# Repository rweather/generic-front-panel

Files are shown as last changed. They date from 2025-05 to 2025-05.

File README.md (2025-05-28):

Generic Front Panel
===================

This repository contains schematics and other information for a generic
front panel for 8-bit homebrew computers.

Here it is connected to my version of
[Ben Eater's 6502 Breadboard Computer](https://eater.net/6502),
running the "hello.s" example from the "src/6502" directory.
It is shown here after I typed ABCDEF on the keypad:

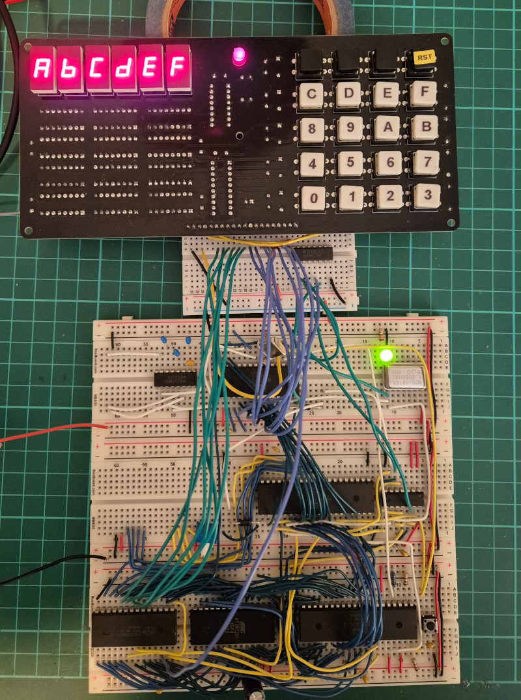
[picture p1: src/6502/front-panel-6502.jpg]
Front Panel Connected to 6502 Computer


Here is a close-up of the front panel with a 3D-printed plate over the top:

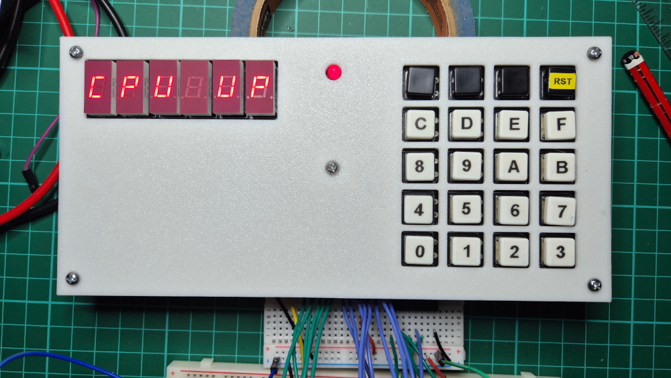
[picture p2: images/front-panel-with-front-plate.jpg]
Front Panel with Front Plate


The "print" directory contains an OpenSCAD file for the 3D-printable plate.
My brother, who is into 3D-printing, has a textured print bed for his printer.
He printed the plate upside down and the texturing gave the plate a nice finish.

## Features

The generic front panel has the following features:

* 6-digit seven segment display.
* 16-digit hexadecimal keypad.
* 3 extra keys for "CMD1", "CMD2", and "CMD3" which can be assigned
  any commands you like by your software.
* 1 extra key for a system reset button.
* 20-pin connector to the rest of your homebrew system.
* Power LED for the 5V power rail.

Note that this front panel requires software support.  It doesn't directly
operate the address bus, data bus, clock, and other control lines like
front panels of old.

What this front panel does do is make it easy to write a memory monitor in
software that can examine memory, modify memory, single-step, and so on.
The 6 displays can display a 16-bit address and an 8-bit byte.  Or anything
else you like, even words.

The seven segment displays, keypad buttons, and power LED are mounted
on the front side of the PCB.  All other components are mounted on the
back side.  The inline current limiting resistors are specified as 8-way
resistor arrays.  However, you could fit 8 regular resistors side by side
instead.

The front panel draws about 250mA from the 5V rail when all 48 segments
in the 7-segment displays and the power LED are lit.  About 5mA per segment.

I have provided drivers and examples for various CPU's under the
"src" directory.  Patches welcome for other CPU's and homebrew boards.

## Schematic and gerber files

* [PDF of the schematic](schematics/Generic_Front_Panel/PDF/Generic_Front_Panel.pdf)
* [Gerber files for manufacture](schematics/Generic_Front_Panel/Gerbers)

The dimensions of the PCB are 195mm x 90mm.  Five 3mm mounting holes are
provided for mounting behind a face plate: four corners and one in the
centre for added strength.

## Parts list

* 1 x Generic Front Panel FP-01 PCB
* 1 x 74HC138 3-line to 8-line decoder (74LS138 or 74HCT138 can be substituted)
* 1 x 74HC244 octal buffer / line driver (74LS244 or 74HCT244 can be substituted)
* 6 x 74HC259 addressable latch (74LS259 or 74HCT239 can be substituted)
* 6 x 100nF ceramic or monolithic capacitor
* 5 x 100pF ceramic capacitor
* 1 x 100uF electrolytic capacitor, rated for 6.3V or better
* 6 x 470 ohm DIP-16 resistor array
* 5 x 4.7K ohm resistor
* 1 x 220 ohm resistor (series resistor for 5mm power LED, adjust value for the LED's current rating)
* 1 x 5mm LED for the power LED (color is up to you)
* 6 x MAN71A 7-segment LED display (TIL-312 or Broadcom 5082-7611 can be substituted)
* 5 x 1N4148 diode
* 20 x 12mm push button plus keycaps
* 1 x 20-pin 2.54mm pitch terminal header or socket for the J1 connector

I recommend using DIP-14 sockets for the 7-segment LED displays to
raise the height of the displays up to roughly level with the top of the
push buttons plus keycaps.  Sockets for the other IC's are up to you;
I didn't bother.

Labels can be applied to the keycaps using a label maker and clear labels.

This is what the front and back of the PCB looks like once assembled
(I had only done a very basic board clean at this point so it is still a
little smudgy):

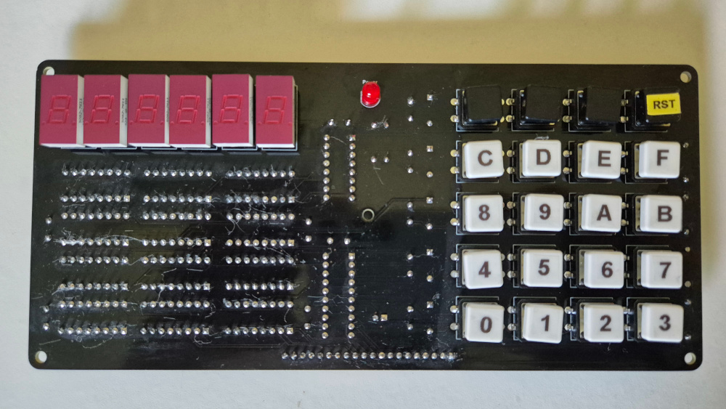
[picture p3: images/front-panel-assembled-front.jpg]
Front Panel Assembled Front


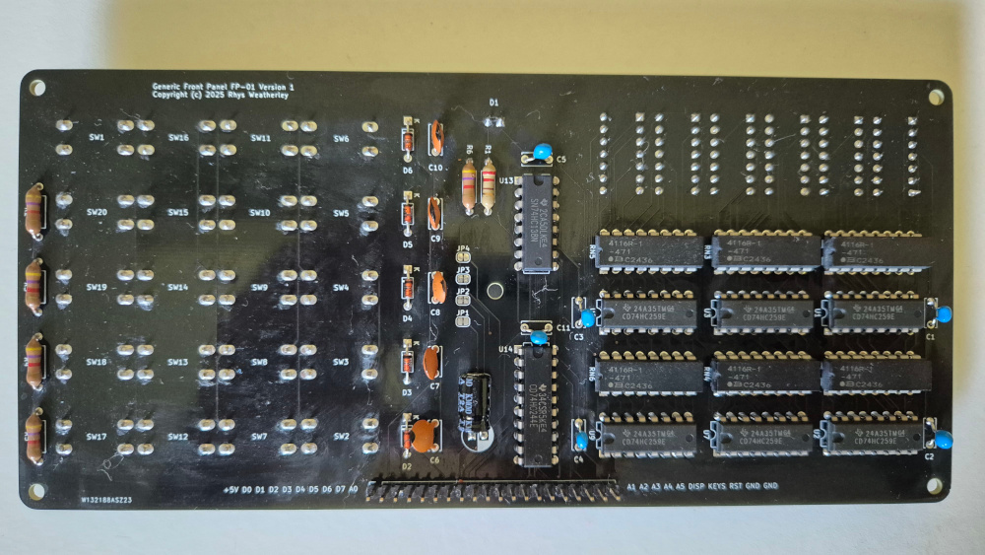
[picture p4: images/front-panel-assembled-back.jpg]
Front Panel Assembled Back


## 20-pin connector

The connector on the bottom of the PCB has the following pins:

<table border="1">
<tr><td><b>Pin</b></td><td><b>Description</b></td></tr>
<tr><td>1</td><td>+5V</td></tr>
<tr><td>2</td><td>D0</td></tr>
<tr><td>3</td><td>D1</td></tr>
<tr><td>4</td><td>D2</td></tr>
<tr><td>5</td><td>D3</td></tr>
<tr><td>6</td><td>D4</td></tr>
<tr><td>7</td><td>D5</td></tr>
<tr><td>8</td><td>D6</td></tr>
<tr><td>9</td><td>D7</td></tr>
<tr><td>10</td><td>A0</td></tr>
<tr><td>11</td><td>A1</td></tr>
<tr><td>12</td><td>A2</td></tr>
<tr><td>13</td><td>A3</td></tr>
<tr><td>14</td><td>A4</td></tr>
<tr><td>15</td><td>A5</td></tr>
<tr><td>16</td><td>Select Display (active low)</td></tr>
<tr><td>17</td><td>Select Keypad (active low)</td></tr>
<tr><td>18</td><td>Reset (active low)</td></tr>
<tr><td>19</td><td>GND</td></tr>
<tr><td>20</td><td>GND</td></tr>
</table>

## Chip selects

To interface to your homebrew computer, you will need to provide address
decoding for the two "chip select" lines "Select Display" and "Select Keypad".

You can put the front panel anywhere in memory or I/O space that is
aligned on a 64-byte boundary.  Only the bottom 6 address bits are
provided to the front panel.  You need to decode the upper 10 bits
(of a 16-bit address) yourself by some means.

"Select Display" should be low when the top-most bits of the address
match the location in memory where you want to put the display,
and when the bus is in a write cycle.  The display occupies 64 bytes
of memory space.

"Select Keypad" should be low when the top-most bits of the address
match the location in memory where you want to put the keypad,
and when the bus is in a read cycle.  The keypad occupies 32 bytes
of memory space.  It can overlap with the display in memory if that
is easier.

## Writing to the display

Each segment of the display has its own memory address.  Each digit
occupies 8 bytes of memory space, for the segments A, B, C, D, E, F, G,
and decimal point.  The displays are at offsets 0, 8, 16, 24, 32,
and 40 in the memory space.

Write a byte with the low bit set to 0 to a segment's address to turn
the segment on, or write a byte with the low bit set to 1 to turn the
segment off.  The segment will stay lit until modified or the power is
turned off.  The display is not multiplexed so there is no need to
constantly refresh.

Writing any byte value to offset 56 will turn all segments on.
This can be useful for testing.  Normally you will want to turn
everything off at startup time.

The "one byte per segment" design was borrowed from the Heathkit ET-3400.
74HC259 addressable latches are used to individually address each segment,
and to remember the state of the segment between writes.

## Reading from the keypad

The keypad consists of 5 rows of 4 keys.  The rows are associated with
address bits A0 to A4.  Scan through the keypad one row at a time,
setting one address bit to 0 and the rest to 1.  When you read from that
address, the bits that are set to zero indicate which keys are pressed
on that row.

<table border="1">
<tr><td><b>Address</b></td><td><b>Bit</b></td><td><b>Key</b></td></tr>
<tr><td>$XX1E (A0)</td><td>0</td><td>0</td></tr>
<tr><td>$XX1E (A0)</td><td>1</td><td>1</td></tr>
<tr><td>$XX1E (A0)</td><td>2</td><td>2</td></tr>
<tr><td>$XX1E (A0)</td><td>3</td><td>3</td></tr>
<tr><td>$XX1D (A1)</td><td>0</td><td>4</td></tr>
<tr><td>$XX1D (A1)</td><td>1</td><td>5</td></tr>
<tr><td>$XX1D (A1)</td><td>2</td><td>6</td></tr>
<tr><td>$XX1D (A1)</td><td>3</td><td>7</td></tr>
<tr><td>$XX1B (A2)</td><td>0</td><td>8</td></tr>
<tr><td>$XX1B (A2)</td><td>1</td><td>9</td></tr>
<tr><td>$XX1B (A2)</td><td>2</td><td>A</td></tr>
<tr><td>$XX1B (A2)</td><td>3</td><td>B</td></tr>
<tr><td>$XX17 (A3)</td><td>0</td><td>C</td></tr>
<tr><td>$XX17 (A3)</td><td>1</td><td>D</td></tr>
<tr><td>$XX17 (A3)</td><td>2</td><td>E</td></tr>
<tr><td>$XX17 (A3)</td><td>3</td><td>F</td></tr>
<tr><td>$XX0F (A4)</td><td>0</td><td>CMD1</td></tr>
<tr><td>$XX0F (A4)</td><td>1</td><td>CMD2</td></tr>
<tr><td>$XX0F (A4)</td><td>2</td><td>CMD3</td></tr>
<tr><td>$XX0F (A4)</td><td>3</td><td>(not used)</td></tr>
</table>

The "Reset" key is special.  It will pull pin 18 on the connector
down to GND when pressed.  It is assumed that a pull-up resistor and
debouncing capacitor are present on your main computer board.
If you want to use "Reset" for something else (such as a "CMD4" key),
you can connect pin 18 to an I/O pin on your main computer board.

The "rows as addresses" design was borrowed from the VZ200 / Laser 200.
Only a single 74HC244 bus transceiver is required to read the keypad.
Everything else is pushbuttons, diodes, resistors, and capacitors.

There are jumpers on the back of the board that can be cut to wire
up additional keys if you need more than 20.  The extra keys will
be available as bits 4 through 7.  The bits are pulled high if the
jumpers are uncut.

## License

MIT License.

## Contact

For more information on this project, to report bugs, or to suggest
improvements, please contact the author Rhys Weatherley via
[email](mailto:rhys.weatherley@gmail.com).

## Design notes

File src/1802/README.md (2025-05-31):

This directory contains driver code for 1802-based machines in "fp\_driver.asm".

The front panel should be wired up to the 1802 microprocessor as follows:

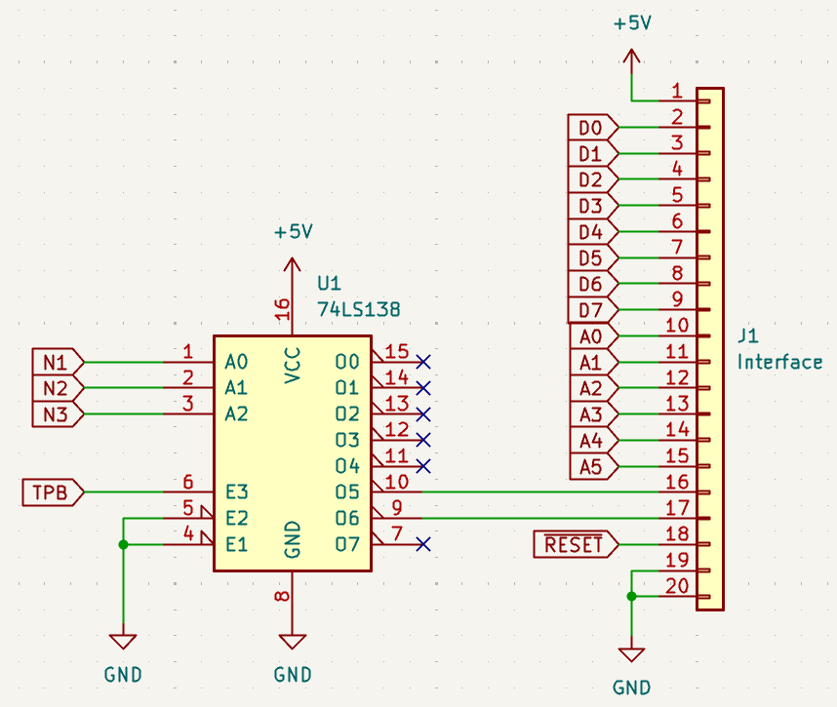
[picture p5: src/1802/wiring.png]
Wiring for 1802


Output 5 is used for the display and input 6 is used for the keypad.
If you change these, then modify the "FP\_PORT\_OUT" and "FP\_PORT\_IN"
definitions in "fp\_driver.asm".

The "hello.asm" example scrolls "HELLORLD!" followed by the printable ASCII
characters across the display from right to left.

Press any key except RESET to stop the scrolling message.  Keys pressed
after that (except RESET) will be shown on the display, scrolling in from
the right.  This allows all keys on the keypad to be tested.  Press RESET
to start again with the scrolling message.

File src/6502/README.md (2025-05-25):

This directory contains driver code for 6502-based machines in "fp\_driver.s".

The "hello.s" example is designed to work with
[Ben Eater's 6502 Breadboard Computer](https://eater.net/6502), with the
front panel placed at address $4000 in memory.  The front panel should be
wired up to the breadboard computer as follows:

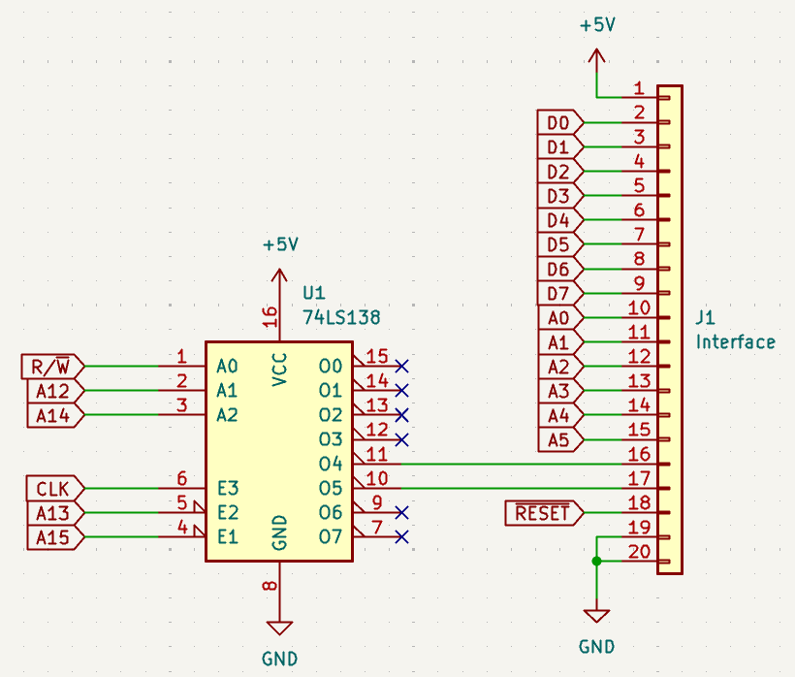
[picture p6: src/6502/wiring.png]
Wiring for 6502


The example scrolls "HELLORLD" followed by the printable ASCII characters
across the display from right to left.

Press any key except RESET to stop the scrolling message.  Keys pressed
after that (except RESET) will be shown on the display, scrolling in from
the right.  This allows all keys on the keypad to be tested.  The three
command keys will be displayed as G, H, and I.

Press RESET to start again with the scrolling message.

Here it is connected to my version of Ben Eater's 6502 Breadboard Computer,
shown here after I typed ABCDEF on the keypad:

Front Panel Connected to 6502 Computer

The "monitor.s" file implements a machine code monitor for 6502 computers
in just 2K of ROM space.  More information is in the
[documentation for the monitor](../../doc/monitor.md).

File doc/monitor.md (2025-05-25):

Front Panel Machine Monitor
===========================

This page describes the operation of the 6502 machine monitor for the
front panel.  The code is located at $F800 in ROM and is just a little
under 2K in size.  The code can be found in the "src/6502/monitor.s"
file in this repository.

## Inspiration

The design of this monitor was inspired by the [Heathkit ET-3400](http://dunfield.classiccmp.org/heath/index.htm).

The Heathkit had 16 hexadecimal keys plus a "Reset" key.  Each of the
hexadecimal keys was assigned a monitor function: "E" for "EXAM" (examine
memory), "F" for "FWD" (move forward one address in memory),
"C" for "CHAN" (change memory), and so on.

The user would press "Reset", select a monitor function, and then type
hexadecimal digits to enter addresses or data, or to run programs.
To select another command, the user would press "Reset" again and repeat.

I made a few adjustments to the workflow to make program entry faster,
but the core idea of the Heathkit's monitor is intact.

## Keypad

The keypad is laid out as follows:

      Func  Prev Next Reset
        C    D    E    F
        8    9    A    B
        4    5    6    7
        0    1    2    3

The "Func" key is used to select monitor functions.

## System Reset

When the system resets due to power on, or pressing the "Reset" button,
the display will show "CPU UP", just like the Heathkit:



Press "Func" to enter the main function menu, or any other key to enter the
default examine/change mode.

## Main Function Menu

The Heathkit used "Reset" to enter the main function menu.  I instead
used one of the three command keys on the front panel.

Press "Func" at any time to enter the main function menu, which will show
"Func" on the display:



From here, the hexadecimal keypad can be used to select a function:

* "A" displays the accumulator and other registers.
* "C" enters the default examine / change mode.
* "D" (or "do") starts executing programs.
* "E" changes the examine address.
* "5" enters single-step mode.

All other keys act the same as "C".  They may be assigned functions
in the future.  The Heathkit also had a function for setting breakpoints.

## Examine / Change

The default function of the monitor is Examine / Change.  The current
address is displayed on-screen, together with the byte value at
that address:



The decimal point acts as a separator between the address and data,
making it easier to see which is which at a glance.

"Next" will move to the next address in memory, and "Prev" will move to the
previous address in memory.

Enter two hexadecimal digits to change the current byte and move onto the
next address in memory.  This allows programs to be entered very quickly.

Upon power up, the starting address is set to $0300 in RAM.  A later
soft reset will retain the current address.

## Change Examine Address

Press "Func" and then "E" to modify the address that is being used to
examine memory.  The current address is displayed:



Press hexadecimal digit keys to modify the address.  Each new digit is
entered at the right of the address, shifting the other digits left.
This is the result after pressing "7" and "8" from the previous state:



Press either "Next" or "Prev" to return to the default Examine / Change
mode at the newly selected address.

## Inspecting and Modifying Registers

Press "Func" and then "A" to inspect the registers starting with the
accumulator.  Use "Next" and "Prev" to move to another register, or
enter hexadecimal digits to alter the register's value.













## Do Mode

Press "Func" and then "D" to enter "do" mode.  The current "PC" value is
displayed on the screen:



Use hexadecimal digits to modify the value of "PC", and then press
"Next" or "Prev" to start executing the code at the address.

When the code returns with a "RTS" instruction, the system will pause
waiting for a key to be pressed.  This allows the user to see the last
thing that the program printed on the display before erasing it and
re-entering the monitor.

## Single Stepping

Press "Func" and then "5" to enter single-step mode.  The current
value of "PC" is displayed, plus the opcode byte at that address:



Pressing either "Next" or "Prev" will step the instruction and then
display the next instruction; and so on.  Pressing any other key will
return to the monitor or function menu.

## Breakpoints

If the program encounters a $00 or "BRK" instruction, it will enter
the monitor and display the address at which the breakpoint occurred:



Press "Func" to go to the main function menu, or any other key to
enter examine / change mode at the breakpoint address.

The monitor doesn't currently offer a method to set and remove breakpoints
like the Heathkit did.  You can however set your own breakpoints by
putting a $00 byte in the code and remembering what the previous byte was
to restore it later.

## Acknowledgements

7-segment display images were generated with the online
[LCD Display Screenshot Generator](https://avtanski.net/projects/lcd/).

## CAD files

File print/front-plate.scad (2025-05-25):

// Configurable parameters.
front_plate_width = 200;
front_plate_height = 95;
front_plate_depth = 2;

// Size of the PCB.
pcb_width = 194.945;
pcb_height = 90.170;

// Derived variables.
offset_x = (front_plate_width - pcb_width) / 2;
offset_y = (front_plate_height - pcb_height) / 2;

// Set the fidelity of round holes.
$fn = 50;

// Show the PCB.
//module PCB()
//{
//    color("green") {
//        translate([offset_x, pcb_height + offset_y, -5]) {
//            import("Generic_Front_Panel_PCB.stl");
//        }
//    }
//}
//PCB();

// Create the front plate.
module FrontPlate() {
    cube([front_plate_width, front_plate_height, front_plate_depth]);
}

// Cylinder to cut out the hole for the power LED.
module LedHole() {
    cylinder(h = front_plate_depth * 4, r = 3, center = true);
}

// Prism to cut out the hole for the LED segment displays.
module SegmentsHole() {
    translate([6.5, 62.5, 0]) {
        cube([71, 22, front_plate_depth * 2]);
    }
}

// Prism to cut out a hole for a push button.
module PushButton() {
    cube([13.5, 13.0, front_plate_depth * 4], center=true);
}

// Cut a row of four push button holes.
hole_sep_x = 49.0 / 3;
hole_sep_y = 60.5 / 4;
module PushButtonRow() {
    PushButton();
    translate([hole_sep_x, 0, 0]) {
        PushButton();
    }
    translate([hole_sep_x * 2, 0, 0]) {
        PushButton();
    }
    translate([hole_sep_x * 3, 0, 0]) {
        PushButton();
    }
}

// Cut five rows of push button holes.
module PushButtonGrid() {
    PushButtonRow();
    translate([0, -hole_sep_y, 0]) {
        PushButtonRow();
    }
    translate([0, -hole_sep_y * 2, 0]) {
        PushButtonRow();
    }
    translate([0, -hole_sep_y * 3, 0]) {
        PushButtonRow();
    }
    translate([0, -hole_sep_y * 4, 0]) {
        PushButtonRow();
    }
}

// Cut a hole for a mounting screw.
module MountingHole() {
    cylinder(h = front_plate_depth * 4, r = 1.6, center = true);
}

// Build the entire front plate with holes cut.
difference() {
    FrontPlate();
    translate([offset_x, offset_y, -front_plate_depth/2]) {
        SegmentsHole();
        translate([97.8, 80, -front_plate_depth / 3]) {
            LedHole();
        }
        translate([129.8, 76.2, 0]) {
            PushButtonGrid();
        }
        translate([3.8, 3.8, 0]) {
            MountingHole();
        }
        translate([3.8, 86.4, 0]) {
            MountingHole();
        }
        translate([191, 3.8, 0]) {
            MountingHole();
        }
        translate([191, 86.4, 0]) {
            MountingHole();
        }
        translate([97.8, 45, 0]) {
            MountingHole();
        }
    }
}

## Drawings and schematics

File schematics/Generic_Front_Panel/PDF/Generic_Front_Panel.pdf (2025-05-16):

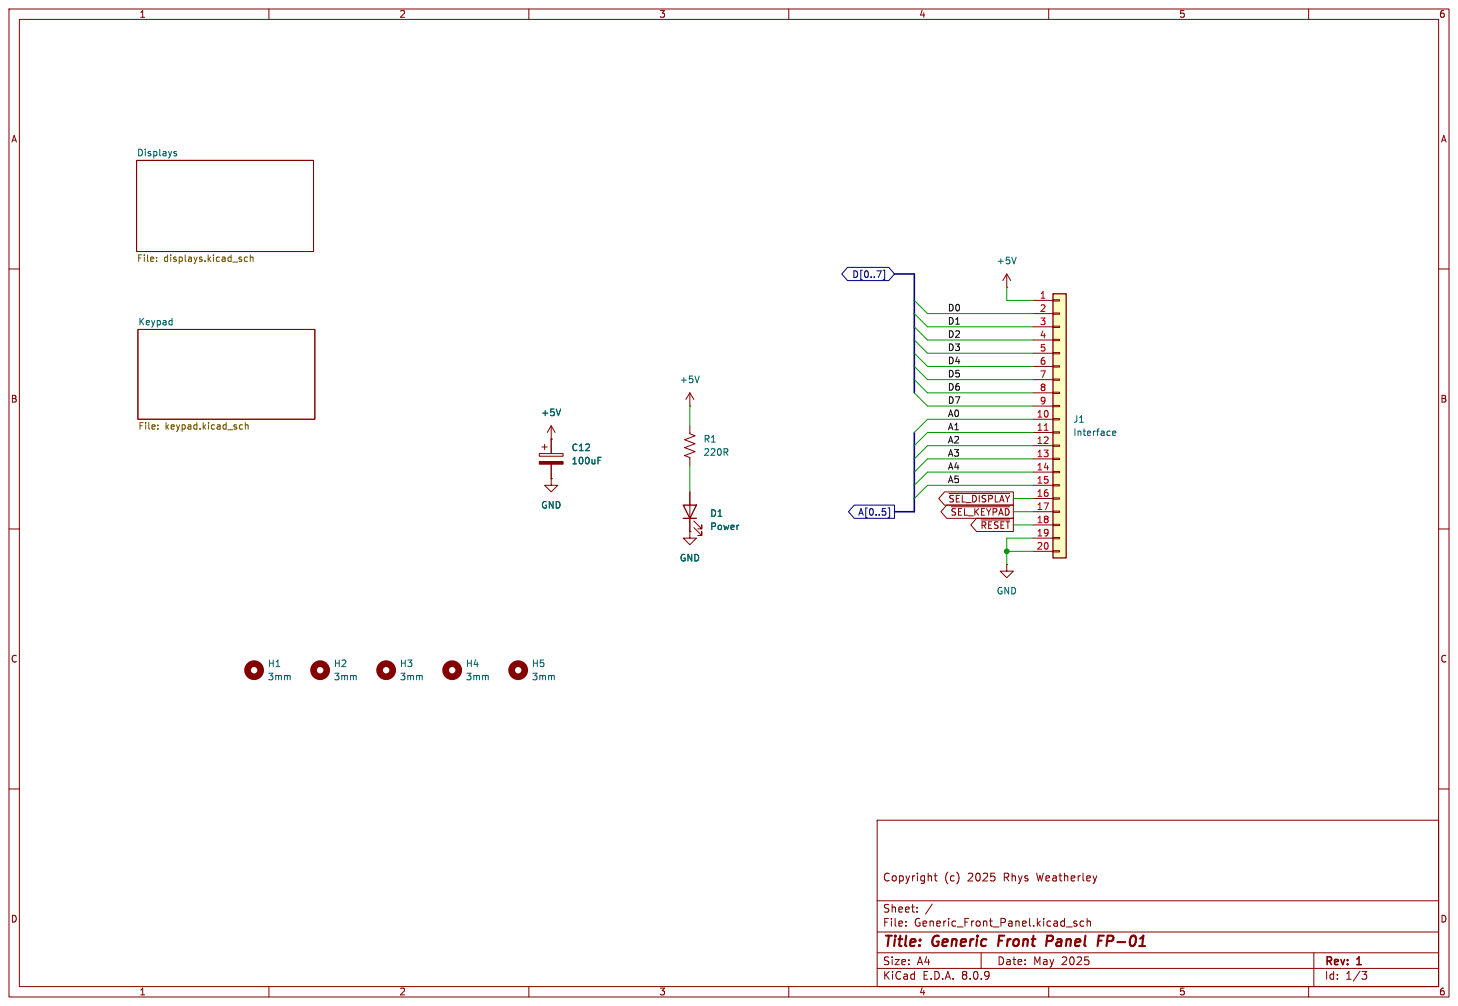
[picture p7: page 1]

Id: 1/3 Title: Generic Front Panel FP-01

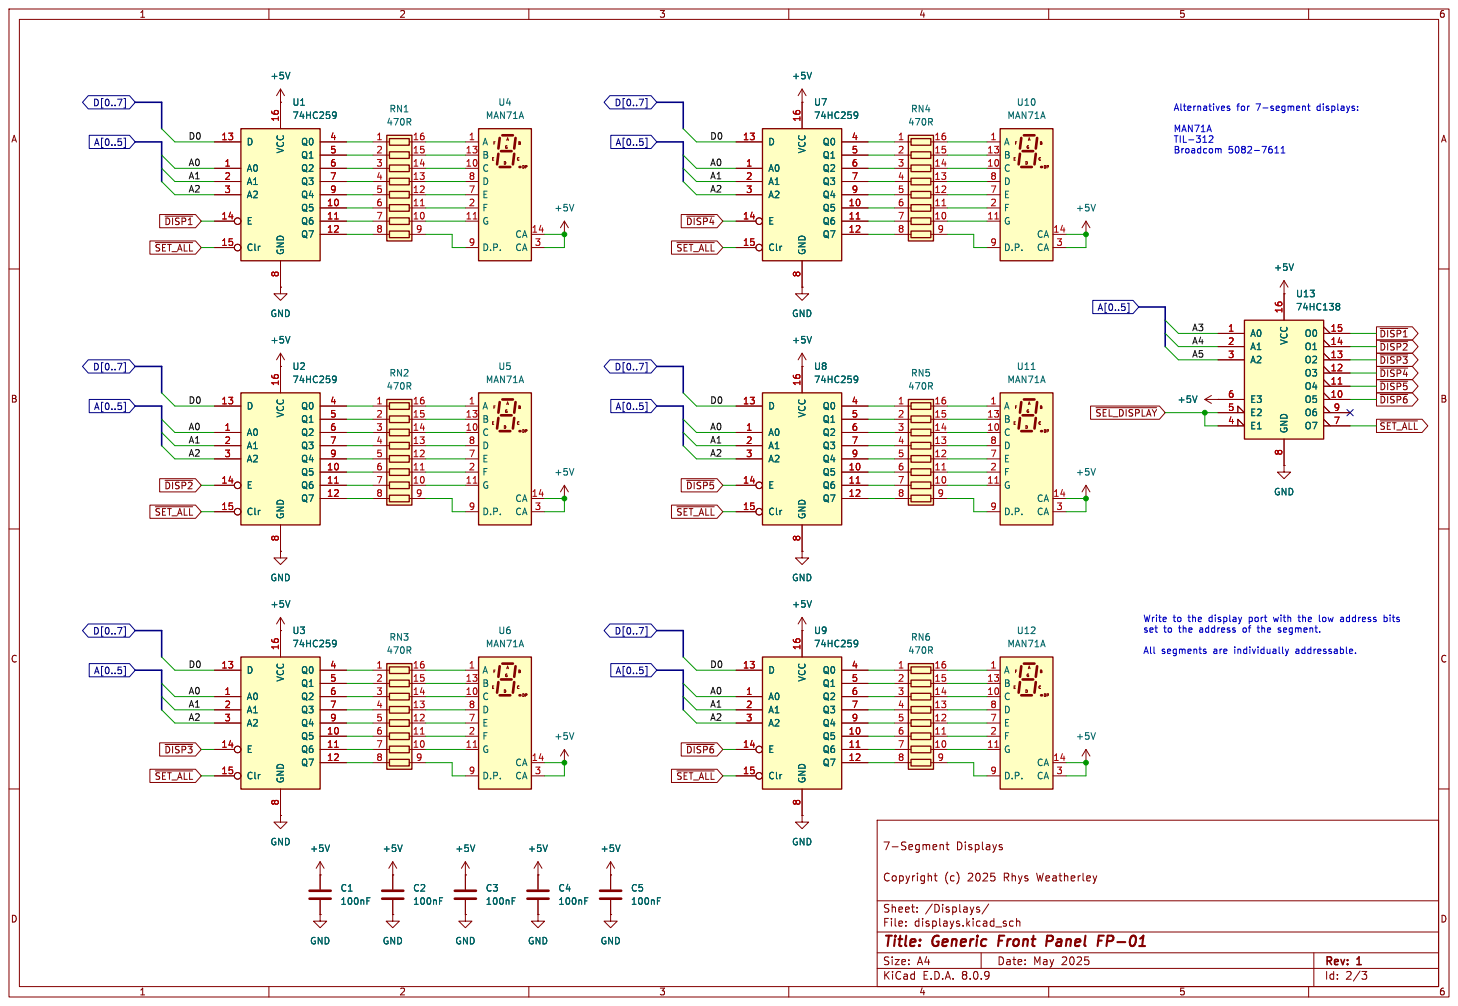
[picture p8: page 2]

File: displays.kicad_sch Sheet: /Displays/
Id: 2/3 Title: Generic Front Panel FP-01

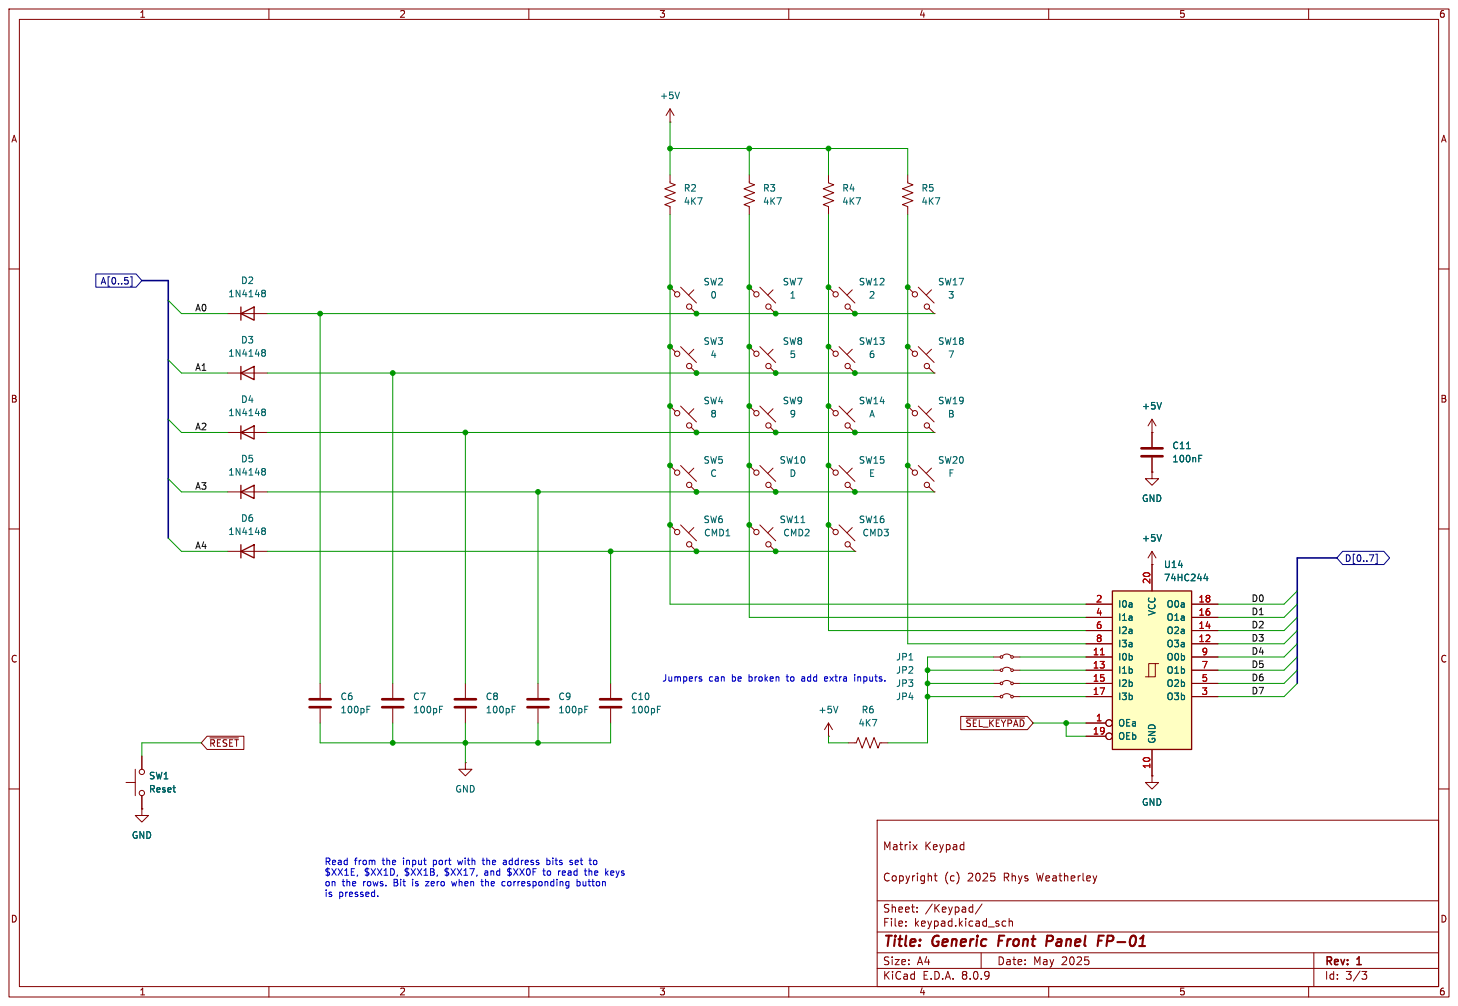
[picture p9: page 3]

Jumpers can be broken to add extra inputs. Read from the input port with the address bits set to

File: keypad.kicad_sch Sheet: /Keypad/
Id: 3/3 Title: Generic Front Panel FP-01

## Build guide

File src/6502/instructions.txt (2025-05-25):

0x00;BRK;brk
0x01;ORA;X,ind
0x04;TSB;zpg;65c02
0x05;ORA;zpg
0x06;ASL;zpg
0x07;RMB;bit,zpg;65sc02
0x08;PHP;
0x09;ORA;#
0x0A;ASL;A
0x0C;TSB;abs;65c02
0x0D;ORA;abs
0x0E;ASL;abs
0x0F;BBR;bit,rel;65sc02
0x10;BPL;rel
0x11;ORA;ind,Y
0x12;ORA;ind,zpg;65c02
0x14;TRB;zpg;65c02
0x15;ORA;zpg,X
0x16;ASL;zpg,X
0x17;RMB;bit,zpg;65sc02
0x18;CLC;
0x19;ORA;abs,Y
0x1A;INC;A;65c02
0x1C;TRB;abs;65c02
0x1D;ORA;abs,X
0x1E;ASL;abs,X
0x1F;BBR;bit,rel;65sc02
0x20;JSR;jsr
0x21;AND;X,ind
0x24;BIT;zpg
0x25;AND;zpg
0x26;ROL;zpg
0x27;RMB;bit,zpg;65sc02
0x28;PLP;
0x29;AND;#
0x2A;ROL;A
0x2C;BIT;abs
0x2D;AND;abs
0x2E;ROL;abs
0x2F;BBR;bit,rel;65sc02
0x30;BMI;rel
0x31;AND;ind,Y
0x32;AND;ind,zpg;65c02
0x34;BIT;zpg,X;65c02
0x35;AND;zpg,X
0x36;ROL;zpg,X
0x37;RMB;bit,zpg;65sc02
0x38;SEC;
0x3A;DEC;A;65c02
0x39;AND;abs,Y
0x3C;BIT;abs,X;65c02
0x3D;AND;abs,X
0x3E;ROL;abs,X
0x3F;BBR;bit,rel;65sc02
0x40;RTI;rti
0x41;EOR;X,ind
0x45;EOR;zpg
0x46;LSR;zpg
0x47;RMB;bit,zpg;65sc02
0x48;PHA;
0x49;EOR;#
0x4A;LSR;A
0x4C;JMP;jmp
0x4D;EOR;abs
0x4E;LSR;abs
0x4F;BBR;bit,rel;65sc02
0x50;BVC;rel
0x51;EOR;ind,Y
0x52;EOR;ind,zpg;65c02
0x55;EOR;zpg,X
0x56;LSR;zpg,X
0x57;RMB;bit,zpg;65sc02
0x58;CLI;
0x59;EOR;abs,Y
0x5A;PHY;;65c02
0x5D;EOR;abs,X
0x5E;LSR;abs,X
0x5F;BBR;bit,rel;65sc02
0x60;RTS;rts
0x61;ADC;X,ind
0x64;STZ;zpg;65c02
0x65;ADC;zpg
0x66;ROR;zpg
0x67;RMB;bit,zpg;65sc02
0x68;PLA;
0x69;ADC;#
0x6A;ROR;A
0x6C;JMP;ind
0x6D;ADC;abs
0x6E;ROR;abs
0x6F;BBR;bit,rel;65sc02
0x70;BVS;rel
0x71;ADC;ind,Y
0x72;ADC;ind,zpg;65c02
0x74;STZ;zpg,X;65c02
0x75;ADC;zpg,X
0x76;ROR;zpg,X
0x77;RMB;bit,zpg;65sc02
0x78;SEI;
0x79;ADC;abs,Y
0x7A;PLY;;65c02
0x7C;JMP;ind,abs,X;65c02
0x7D;ADC;abs,X
0x7E;ROR;abs,X
0x7F;BBR;bit,rel;65sc02
0x80;BRA;rel;65c02
0x81;STA;X,ind
0x84;STY;zpg
0x85;STA;zpg
0x86;STX;zpg
0x87;SMB;bit,zpg;65sc02
0x88;DEY;
0x89;BIT;imm;65c02
0x8A;TXA;
0x8C;STY;abs
0x8D;STA;abs
0x8E;STX;abs
0x8F;BBS;bit,rel;65sc02
0x90;BCC;rel
0x91;STA;ind,Y
0x92;STA;ind,zpg;65c02
0x94;STY;zpg,X
0x95;STA;zpg,X
0x96;STX;zpg,Y
0x97;SMB;bit,zpg;65sc02
0x98;TYA;
0x99;STA;abs,Y
0x9A;TXS;
0x9C;STZ;abs;65c02
0x9D;STA;abs,X
0x9E;STZ;abs,X;65c02
0x9F;BBS;bit,rel;65sc02
0xA0;LDY;imm
0xA1;LDA;X,ind
0xA2;LDX;imm
0xA4;LDY;zpg
0xA5;LDA;zpg
0xA6;LDX;zpg
0xA7;SMB;bit,zpg;65sc02
0xA8;TAY;
0xA9;LDA;imm
0xAA;TAX;
0xAC;LDY;abs
0xAD;LDA;abs
0xAE;LDX;abs
0xAF;BBS;bit,rel;65sc02
0xB0;BCS;rel
0xB1;LDA;ind,Y
0xB2;LDA;ind,zpg;65c02
0xB4;LDY;zpg,X
0xB5;LDA;zpg,X
0xB6;LDX;zpg,Y
0xB7;SMB;bit,zpg;65sc02
0xB8;CLV;
0xB9;LDA;abs,Y
0xBA;TSX;
0xBC;LDY;abs,X
0xBD;LDA;abs,X
0xBE;LDX;abs,Y
0xBF;BBS;bit,rel;65sc02
0xC0;CPY;imm
0xC1;CMP;X,ind
0xC4;CPY;zpg
0xC5;CMP;zpg
0xC6;DEC;zpg
0xC7;SMB;bit,zpg;65sc02
0xC8;INY;
0xC9;CMP;imm
0xCA;DEX;
0xCB;WAI;;wdc65c02
0xCC;CPY;abs
0xCD;CMP;abs
0xCE;DEC;abs
0xCF;BBS;bit,rel;65sc02
0xD0;BNE;rel
0xD1;CMP;ind,Y
0xD2;CMP;ind,zpg;65c02
0xD5;CMP;zpg,X
0xD6;DEC;zpg,X
0xD7;SMB;bit,zpg;65sc02
0xD8;CLD;
0xD9;CMP;abs,Y
0xDA;PHX;;65c02
0xDB;STP;;wdc65c02
0xDD;CMP;abs,X
0xDE;DEC;abs,Y
0xDF;BBS;bit,rel;65sc02
0xE0;CPX;imm
0xE1;SBC;X,ind
0xE4;CPX;zpg
0xE5;SBC;zpg
0xE6;INC;zpg
0xE7;SMB;bit,zpg;65sc02
0xE8;INX;
0xE9;SBC;imm
0xEA;NOP;
0xEC;CPX;abs
0xED;SBC;abs
0xEE;INC;abs
0xEF;BBS;bit,rel;65sc02
0xF0;BEQ;rel
0xF1;SBC;ind,Y
0xF2;SBC;ind,zpg;65c02
0xF5;SBC;zpg,X
0xF6;INC;zpg,X
0xF7;SMB;bit,zpg;65sc02
0xF8;SED;
0xF9;SBC;abs,Y
0xFA;PLX;;65c02
0xFD;SBC;abs,X
0xFE;INC;abs,Y
0xFF;BBS;bit,rel;65sc02

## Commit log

2025-05-10 Schematics and PCB layout for the generic front panel
    [Generic_Front_Panel-B_Cu.gbl, Generic_Front_Panel-B_Mask.gbs, Generic_Front_Panel-B_Paste.gbp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]
2025-05-11 Front panel driver for 6502-based computers
    [Wiring_for_6502.kicad_pcb, Wiring_for_6502.kicad_sch]
2025-05-13 Front panel driver for 1802-based computers
2025-05-14 Make the 1802 driver more position-independent for I/O mapping
2025-05-16 Update filter capacitor to 100uF
    [Generic_Front_Panel.kicad_pcb, Generic_Front_Panel.kicad_sch]
2025-05-16 Document the maximum current draw of the panel
2025-05-17 Debouncing key presses in the 6502 version of the driver
2025-05-18 Add more README material and pictures of the front and back of the PCB
2025-05-25 OpenSCAD file for a 3D-printable front plate for the panel
    [front-plate.scad]
2025-05-25 Simplify the driver code
2025-05-28 Picture of the 3D-printed front plate
2025-05-31 Get the 1802 version of the front panel driver to work
    [Wiring_for_1802.kicad_pcb, Wiring_for_1802.kicad_sch]
